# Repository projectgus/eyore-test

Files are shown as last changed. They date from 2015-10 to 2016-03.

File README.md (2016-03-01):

# Eyore-Test

A hardware design for running automated tests against the esp-open-rtos ESP8266-based software framework.

# Major Components

* 2x ESP-12E ESP8266 processor modules, to run tests on. Named A & B.
* 1x STM32F072C8 Cortex M0 microcontroller - acts as USB serial for programming & monitoring, also provides a "programmable peripheral" to test against.
* Host computer with esp-open-rtos source tree, including host test program (`test_runner.py`).

# Cost

Aim is for total BOM cost under $12US for small quantities, all inclusive.

# Functional Description

## Programming/Initialisation

STM32F072 acts as USB device (dual CDC ACM serial port). STM32 USART1 connects to ESP A's TX/RX pins, USART2 to ESP B TX/RX pins.

Other STM32 I/O pins are wired to drive RESET and GPIO0 on both ESP A & ESP B. This allows the STM32 to reset the ESPs & select either serial bootloading or normal operation.

The USB CDC interface provides a "NodeMCU-compatible" reset protocol that works with esptool.py - asserting DTR pulls down GPIO0, asserting RTS pulls down RESET, but asserting both DTR and RTS together does nothing.

## ESP A / ESP B Connections

These connections match the "dual" configuration mentioned in the esp-open-rtos test_setup docs. These allow the ESPs to interact with each other during tests.

This part of the test setup can be reproduced on a breadboard fairly easily.

ESP A & B have the following interconncted pins, all via 220 ohm resistors for short circuit protection:

ESP A | ESP B | Function
----- | ------  --------
2     | 2     |
4     | 4     |
5     | 5     |
12    | 12    |
13    | 15    | ESP UART RX/TX "swapped"
15    | 13    | ESP UART TX/RX "swapped"
14    | 14    |

Note that GPIOs on ESP A are also connected to the STM32.

## ESP A / STM32 Connections

To allow peripheral testing between ESP A and an independent microcontroller, some STM32 peripherals are connected to ESP A peripherals:

ESP A Interface | ESP GPIOs              | STM32 Interface | ESP Pins
--------------- | ---------------------- | ---------------- | ----------------
Software i2c    | 4, 5                   | I2C1             | PB6, PB7 [1]
HSPI            | 12-15                  | SPI1             | PA4-PA7
I2S Input       | 14(WS),13(BCK),12(DAT) | I2S1             | PA15, PB3, PB5
I2S Output      | 2(WS),3(DAT),14(CLK)   | N/A (bit-bang)   | PB11, PA9, PA4 [2]
SPI (flash intf)|                        | SPI2             | PB12..PB15 [3]
ADC (TOUT)      | TOUT                   | GPIO (bit-bang)  | PA0 & PB4 [4]

[1] I2C1 slave is the only STM32 interface enabled after reset, and is the protocol used for the ESP itself to configure the STM32 as a "programmable peripheral".

[2] ESP I2S output is not wired to a I2S peripheral on the STM32. However STM32 can bit-bang reading of the I2S output (at slow clock speeds).

[3] Not used due to hardware bug: On Rev 1.0 of eyore-test the SPI2 NSS pin (slave select) is wired to the CS line of the ESP module, which is the CS line for the ESP's SPI flash. The other SPI2 NSS pin is not connected in this revision.

[4] TOUT pin is connected directly to STM ADC pin PA0. TOUT is also connected to PB4 via an RC network, so PB4 can be used as a low-fi DAC, PWMing a voltage for the ADC to read.

## Programmable Peripheral Interface

As part of each test, ESP A can configure the STM32 peripherals via the I2C interface.

Actual I2C protocol/register details are TBD, likely to be incremental features.

# STM32 Firmware

STM32 has a USB DFU bootloader in ROM. "Flash" button and jumper are provided to access this bootloader on power-on. SWD port is also provided for external programming/debugging if necessary.

# Name

I've seen esp-open-rtos abbreviated to "e-o-r", and I tend to read that as "Eyore". :)

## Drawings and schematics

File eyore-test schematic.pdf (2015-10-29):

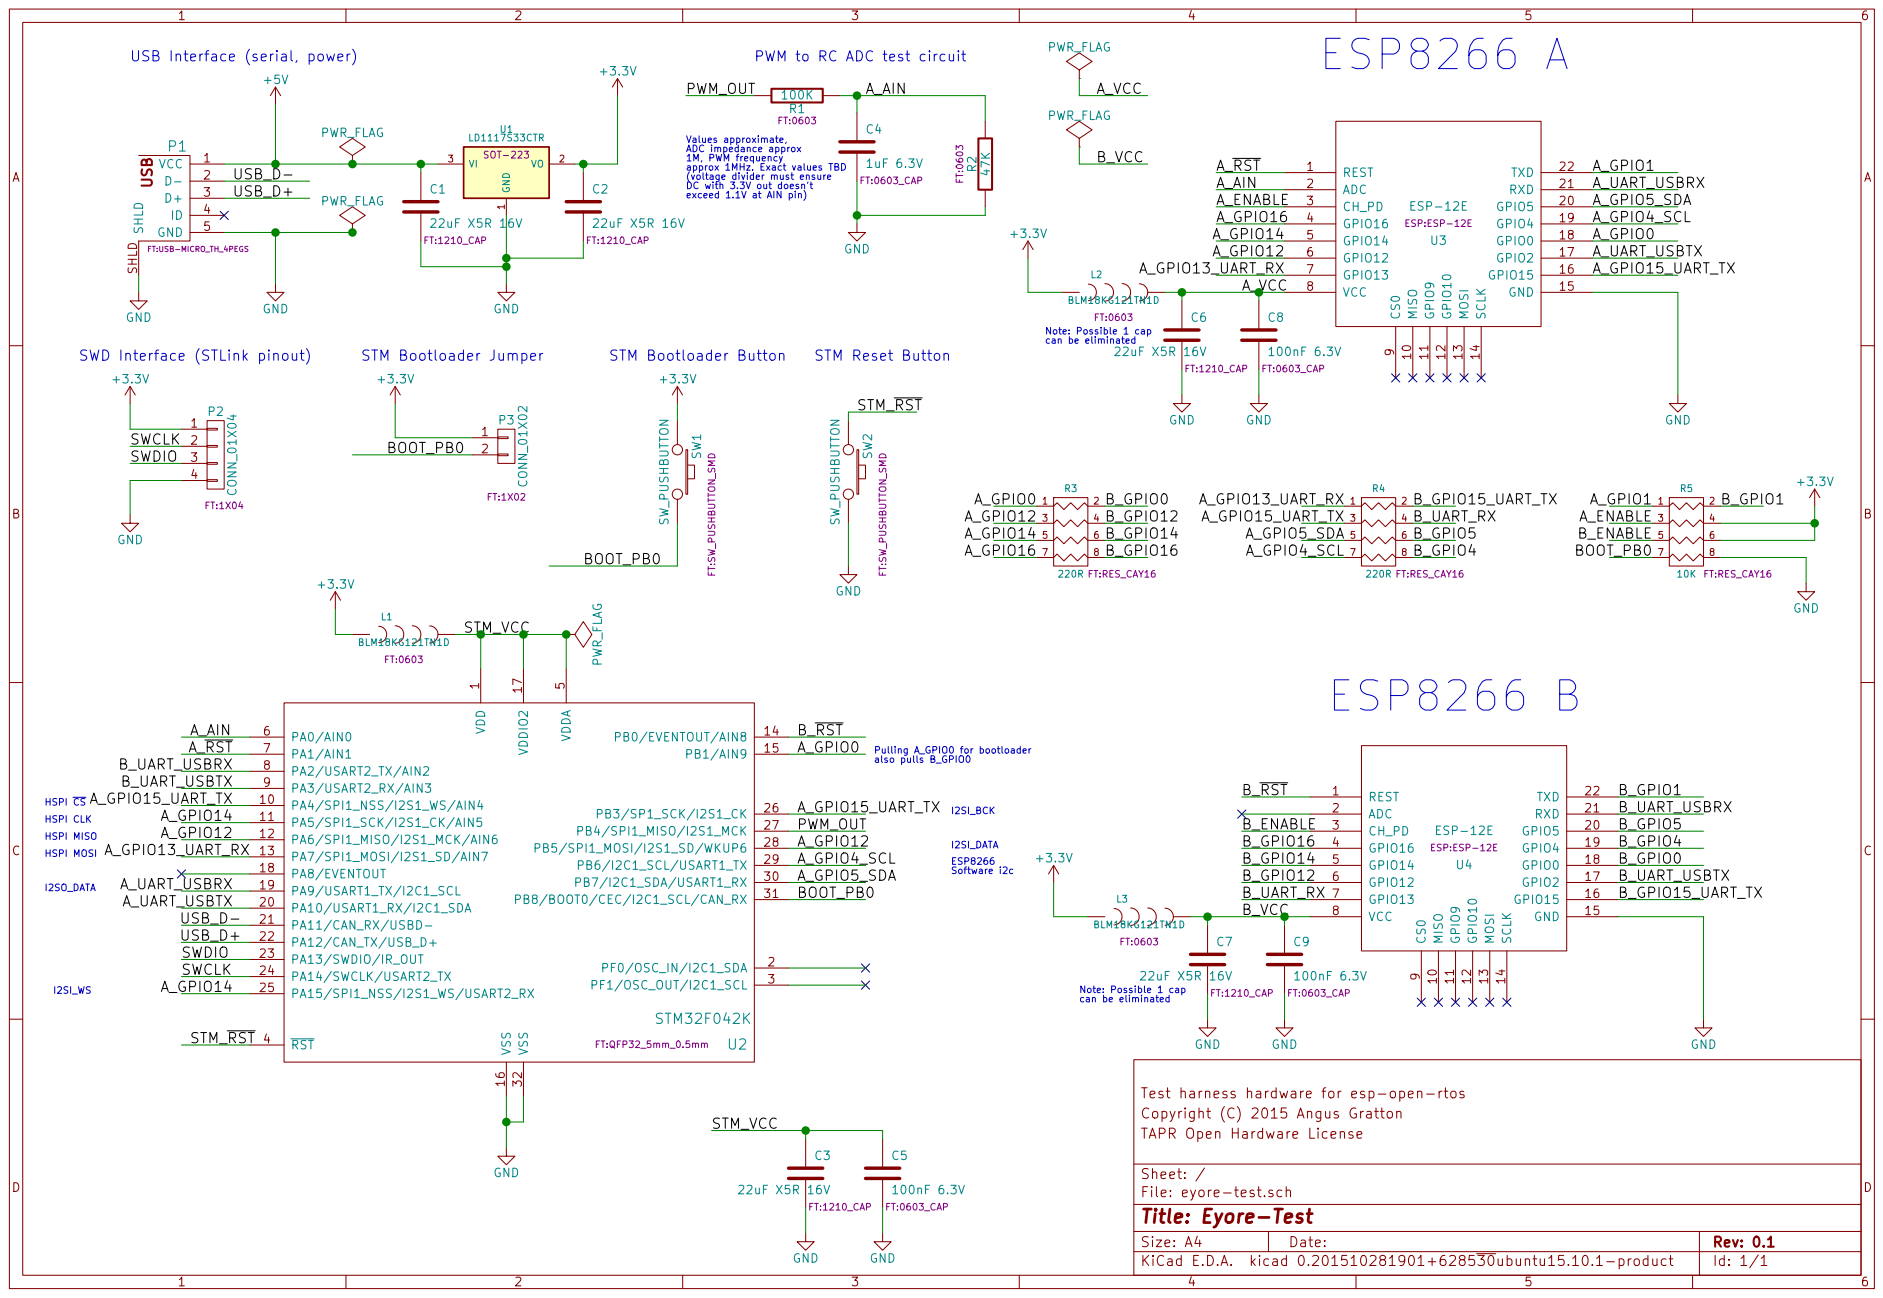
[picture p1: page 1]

FT:0603_CAP PWM to RC ADC test circuit GND

Values approximate, ADC impedance approx 1M, PWM frequency approx 1MHz. Exact values TBD

9 MISO 10 GPIO5 20 GPIO9 11 RXD 21 GPIO10 12 TXD 22 MOSI 13 SCLK 14 GND 15 GPIO15 16 GPIO2 17 GPIO0 18 GPIO4 19 U3 ESP-12E

SWD Interface (STLink pinout)
FT:1X04 +3.3V GNDSWCLK

Pulling A_GPIO0 for bootloader also pulls B_GPIO0 +3.3V

5 PA0/AIN0 6 PA1/AIN1 7 PA2/USART2_TX/AIN2 8 PA3/USART2_RX/AIN3 9 PA4/SPI1_NSS/I2S1_WS/AIN4 10 PA10/USART1_RX/I2C1_SDA 20 PB7/I2C1_SDA/USART1_RX 30 PA5/SPI1_SCK/I2S1_CK/AIN5 11 PA11/CAN_RX/USBD- 21 PB8/BOOT0/CEC/I2C1_SCL/CAN_RX 31 PA6/SPI1_MISO/I2S1_MCK/AIN6 12 PA12/CAN_TX/USB_D+ 22 VSS 32 PA7/SPI1_MOSI/I2S1_SD/AIN7 13 PA13/SWDIO/IR_OUT 23 PB0/EVENTOUT/AIN8 14 PA14/SWCLK/USART2_TX 24 PB1/AIN9 15 PA15/SPI1_NSS/I2S1_WS/USART2_RX 25 VSS 16 PB3/SP1_SCK/I2S1_CK 26 VDDIO2 17 PB4/SPI1_MISO/I2S1_MCK 27 PA8/EVENTOUT 18 PB5/SPI1_MOSI/I2S1_SD/WKUP6 28 PA9/USART1_TX/I2C1_SCL 19 PB6/I2C1_SCL/USART1_TX 29 U2 STM32F042K

Test harness hardware for esp-open-rtos VDD

9 MISO 10 GPIO5 20 GPIO9 11 RXD 21 GPIO10 12 TXD 22 MOSI 13 SCLK 14 GND 15 GPIO15 16 GPIO2 17 GPIO0 18 GPIO4 19 U4 ESP-12E

Copyright (C) 2015 Angus Gratton
File: eyore-test.sch Sheet: / TAPR Open Hardware License

Id: 1/1 Title: Eyore-Test

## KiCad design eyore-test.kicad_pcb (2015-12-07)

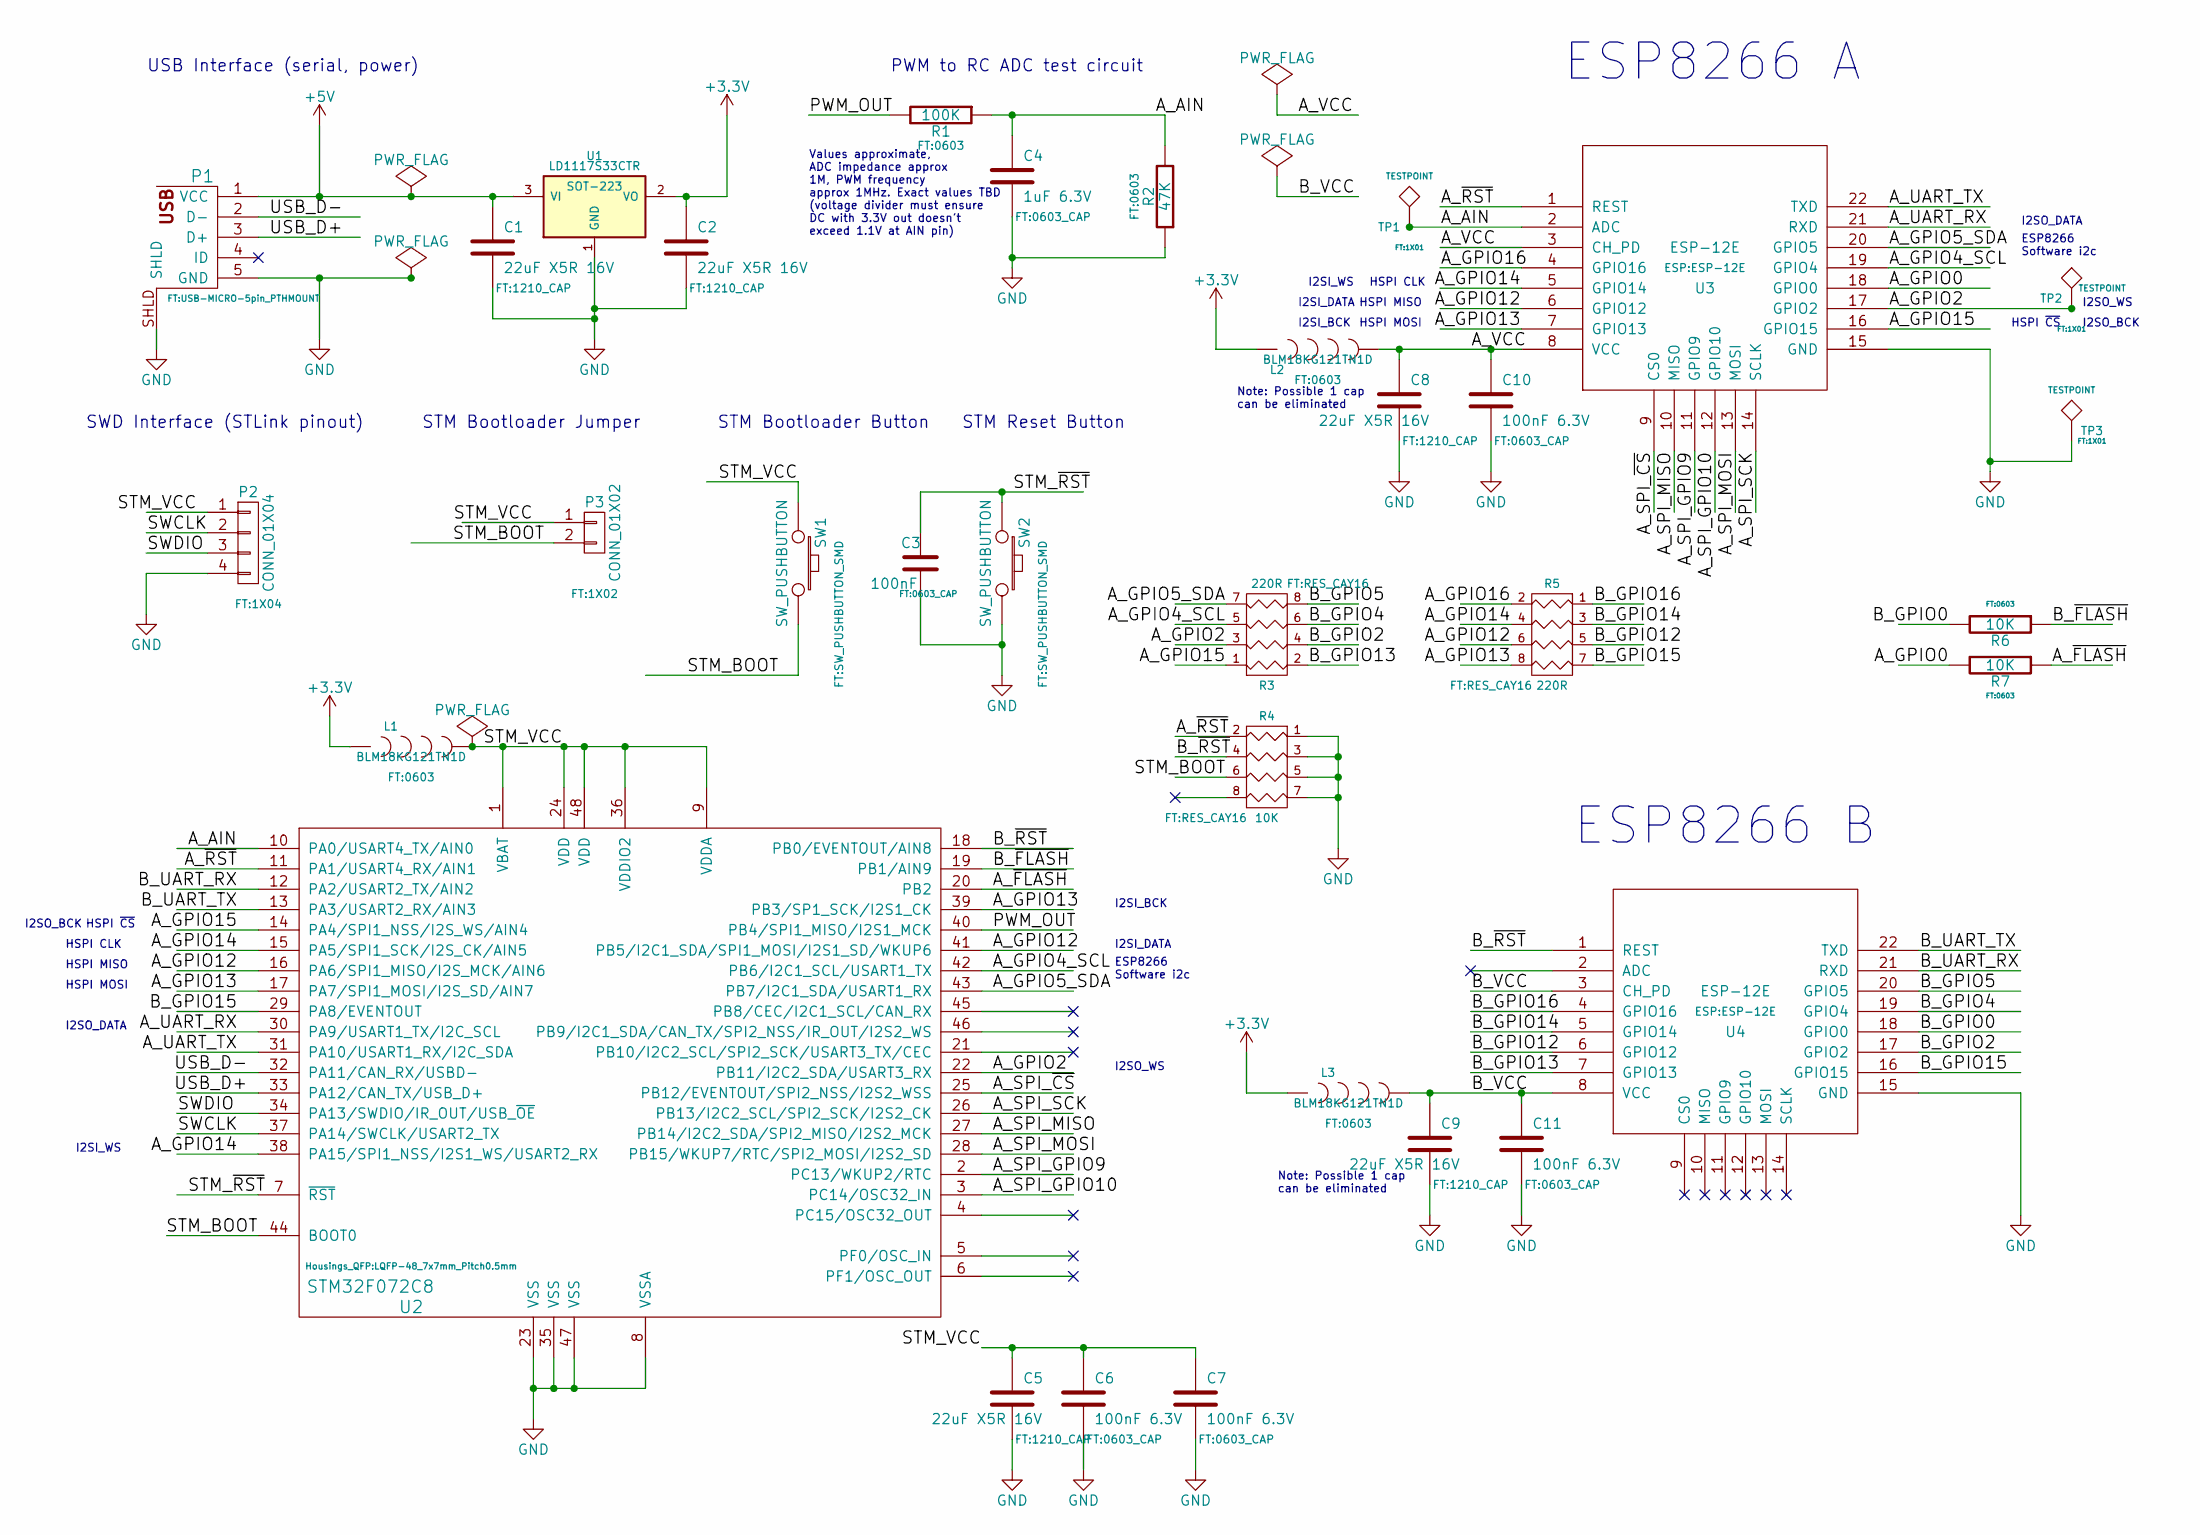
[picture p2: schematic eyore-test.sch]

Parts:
C1, C2, C5, C8, C9: 22uF X5R 16V; 1210_CAP
C3: 100nF; 0603_CAP
C4: 1uF 6.3V; 0603_CAP
C6, C7, C10, C11: 100nF 6.3V; 0603_CAP
L1, L2, L3: BLM18KG121TN1D; 0603
P1: USB_5PIN_SHELL; USB-MICRO-5pin_PTHMOUNT
P2: CONN_01X04; 1X04
P3: CONN_01X02; 1X02
R1: 100K; 0603
R2: 47K; 0603
R3, R5: 220R; RES_CAY16
R4: 10K; RES_CAY16
R6, R7: 10K; 0603
SW1, SW2: SW_PUSHBUTTON; SW_PUSHBUTTON_SMD
TP1, TP2, TP3: TESTPOINT; 1X01
U1: LD1117S33CTR; SOT-223
U2: STM32F072C8; LQFP-48_7x7mm_Pitch0.5mm
U3, U4: ESP-12E

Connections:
+3V3: C2.1, L1.1, L2.1, L3.1, U1.2 (VO)
+5V: C1.1, P1.1 (VCC), U1.3 (VI)
/A_AIN: C4.1, R1.1, R2.2, TP1.1, U2.10 (PA0/USART4_TX/AIN0), U3.2 (ADC)
/A_GPIO0: R7.2, U3.18 (GPIO0)
/A_GPIO2: R3.3 (P2), TP2.1, U2.22 (PB11/I2C2_SDA/USART3_RX), U3.17 (GPIO2)
/A_GPIO4_SCL: R3.5 (P3), U2.42 (PB6/I2C1_SCL/USART1_TX), U3.19 (GPIO4)
/A_GPIO5_SDA: R3.7 (P4), U2.43 (PB7/I2C1_SDA/USART1_RX), U3.20 (GPIO5)
/A_GPIO12: R5.6 (R3), U2.16 (PA6/SPI1_MISO/I2S_MCK/AIN6), U2.41 (PB5/I2C1_SDA/SPI1_MOSI/I2S1_SD/WKUP6), U3.6 (GPIO12)
/A_GPIO13: R5.8 (R4), U2.17 (PA7/SPI1_MOSI/I2S_SD/AIN7), U2.39 (PB3/SP1_SCK/I2S1_CK), U3.7 (GPIO13)
/A_GPIO14: R5.4 (R1), U2.15 (PA5/SPI1_SCK/I2S_CK/AIN5), U2.38 (PA15/SPI1_NSS/I2S1_WS/USART2_RX), U3.5 (GPIO14)
/A_GPIO15: R3.1, U2.14 (PA4/SPI1_NSS/I2S_WS/AIN4), U3.16 (GPIO15)
/A_GPIO16: R5.2 (R1), U3.4 (GPIO16)
/A_SPI_GPIO9: U2.2 (PC13/WKUP2/RTC), U3.11 (GPIO9)
/A_SPI_GPIO10: U2.3 (PC14/OSC32_IN), U3.12 (GPIO10)
/A_SPI_MISO: U2.27 (PB14/I2C2_SDA/SPI2_MISO/I2S2_MCK), U3.10 (MISO)
/A_SPI_MOSI: U2.28 (PB15/WKUP7/RTC/SPI2_MOSI/I2S2_SD), U3.13 (MOSI)
/A_SPI_SCK: U2.26 (PB13/I2C2_SCL/SPI2_SCK/I2S2_CK), U3.14 (SCLK)
/A_SPI_~CS: U2.25 (PB12/EVENTOUT/SPI2_NSS/I2S2_WSS), U3.9 (CS0)
/A_UART_RX: U2.30 (PA9/USART1_TX/I2C_SCL), U3.21 (RXD)
/A_UART_TX: U2.31 (PA10/USART1_RX/I2C_SDA), U3.22 (TXD)
/A_VCC: C8.1, C10.1, L2.2, U3.3 (CH_PD), U3.8 (VCC)
/A_~FLASH: R7.1, U2.20 (PB2)
/A_~RST: R4.2 (R1), U2.11 (PA1/USART4_RX/AIN1), U3.1 (REST)
/B_GPIO0: R6.2, U4.18 (GPIO0)
/B_GPIO2: R3.4 (R1), U4.17 (GPIO2)
/B_GPIO4: R3.6 (R3), U4.19 (GPIO4)
/B_GPIO5: R3.8 (R4), U4.20 (GPIO5)
/B_GPIO12: R5.5 (P3), U4.6 (GPIO12)
/B_GPIO13: R3.2 (R1), U4.7 (GPIO13)
/B_GPIO14: R5.3 (P2), U4.5 (GPIO14)
/B_GPIO15: R5.7 (P4), U2.29 (PA8/EVENTOUT), U4.16 (GPIO15)
/B_GPIO16: R5.1, U4.4 (GPIO16)
/B_UART_RX: U2.12 (PA2/USART2_TX/AIN2), U4.21 (RXD)
/B_UART_TX: U2.13 (PA3/USART2_RX/AIN3), U4.22 (TXD)
/B_VCC: C9.1, C11.1, L3.2, U4.3 (CH_PD), U4.8 (VCC)
/B_~FLASH: R6.1, U2.19 (PB1/AIN9)
/B_~RST: R4.4 (R1), U2.18 (PB0/EVENTOUT/AIN8), U4.1 (REST)
/PWM_OUT: R1.2, U2.40 (PB4/SPI1_MISO/I2S1_MCK)
/STM_BOOT: P3.2, R4.6 (R3), SW1.2, U2.44 (BOOT0)
/STM_VCC: C5.1, C6.1, C7.1, L1.2, P2.1, P3.1, SW1.1, U2.1 (VBAT), U2.9 (VDDA), U2.24 (VDD), U2.36 (VDDIO2), U2.48 (VDD)
/STM_~RST: C3.1, SW2.1, U2.7 (~RST)
/SWCLK: P2.2, U2.37 (PA14/SWCLK/USART2_TX)
/SWDIO: P2.3, U2.34 (PA13/SWDIO/IR_OUT/USB_~OE)
/USB_D+: P1.3 (D+), U2.33 (PA12/CAN_TX/USB_D+)
/USB_D-: P1.2 (D-), U2.32 (PA11/CAN_RX/USBD-)
GND: C1.2, C2.2, C3.2, C4.2, C5.2, C6.2, C7.2, C8.2, C9.2, C10.2, C11.2, P1.5 (GND), P1.SHLD, P2.4, R2.1, R4.1, R4.3 (P2), R4.5 (P3), R4.7 (P4), SW2.2, TP3.1, U1.1 (GND), U2.8 (VSSA), U2.23 (VSS), U2.35 (VSS), U2.47 (VSS), U3.15 (GND), U4.15 (GND)

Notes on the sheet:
SWD Interface (STLink pinout)
USB Interface (serial, power)
ESP8266 A
ESP8266 B
Note: Possible 1 cap can be eliminated
STM Bootloader Jumper
PWM to RC ADC test circuit
Values approximate, ADC impedance approx 1M, PWM frequency approx 1MHz. Exact values TBD (voltage divider must ensure DC with 3.3V out doesn't exceed 1.1V at AIN pin)
HSPI CLK
HSPI MISO
HSPI MOSI
HSPI ~CS
I2SI_DATA
I2SO_DATA
ESP8266 Software i2c
I2SI_WS
STM Bootloader Button
STM Reset Button
I2SO_BCK
I2SI_BCK
I2SI_BCK
I2SO_WS

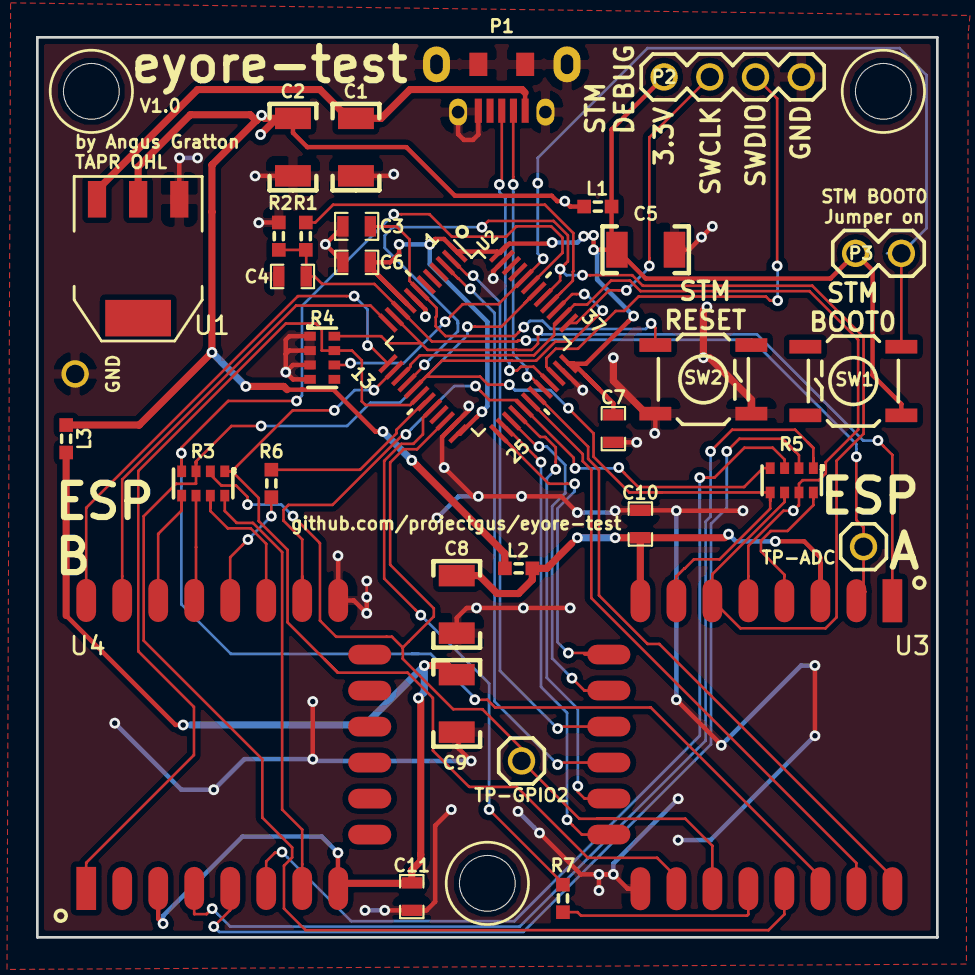
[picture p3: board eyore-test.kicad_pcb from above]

Board: 2 copper layers, 50.0 x 50.0 mm, 36 parts (0 on the bottom side), 46 nets.

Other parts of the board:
1pin, 1pin#2, 1pin#3: VAL**; 1pin

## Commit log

2015-10-29 Initial commit, partial schematic
    [esp-testhw.kicad_pcb, esp-testhw.sch]
2015-10-29 Finished schematic draft
    [esp-testhw.sch]
2015-10-29 Add README, schematic PDF
    [eyore-test.sch]
2015-11-10 Swap STM32F042K for larger STM32F042C, allow routing of ESP SPI port to second STM SPI
    [eyore-test.sch]
2015-11-15 Simplify UART wiring, general cleanup
    [eyore-test.sch]
2015-11-17 First cut at component layout
    [eyore-test.kicad_pcb, eyore-test.sch]
2015-12-01 Part routed, but I think approach was wrong
    [eyore-test.kicad_pcb, eyore-test.sch]
2015-12-06 Routed 4 layer version
    [eyore-test.kicad_pcb, eyore-test.sch]
2015-12-06 Rerouted as 2 layers
    [eyore-test.kicad_pcb]
2015-12-06 Ready for V0.1 prototype
    [eyore-test.kicad_pcb]
2015-12-07 V1.0 as ordered
    [eyore-test.kicad_pcb, eyore-test.sch]
2015-12-07 Move github URL to somewhere that won't be covered by capacitors
    [eyore-test.kicad_pcb]
2016-03-01 Update README to match the actual boards that were made
